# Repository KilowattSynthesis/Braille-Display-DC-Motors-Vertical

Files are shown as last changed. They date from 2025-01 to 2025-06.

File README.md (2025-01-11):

# Braille-Display-DC-Motors-Vertical

Braille display POC using 0408 DC motors, vertically inline under each dot, to spin a bolt for each dot. Includes CAD, PCB, and Firmware. 

**Type 5:** Vertical DC motors.

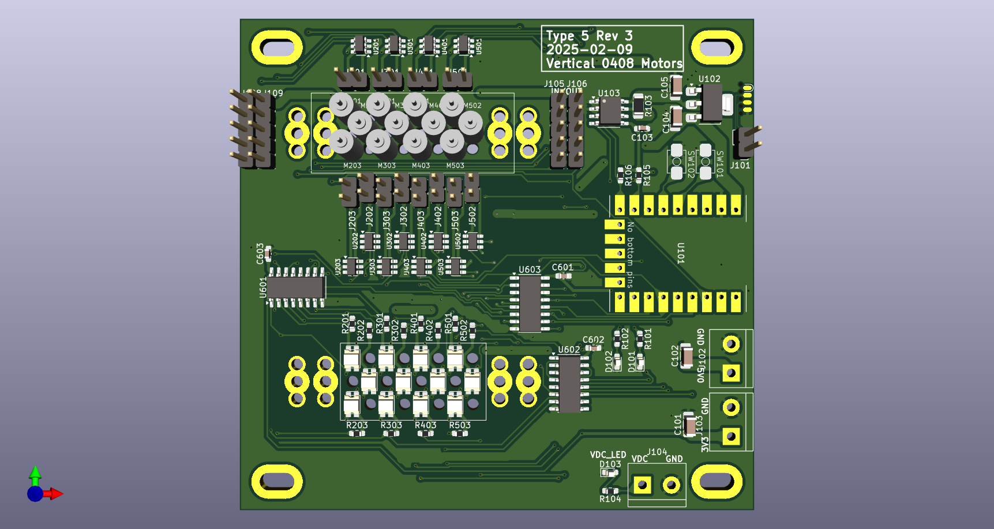
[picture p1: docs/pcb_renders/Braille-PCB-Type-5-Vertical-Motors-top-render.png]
Type 5 PCB Top Side Render


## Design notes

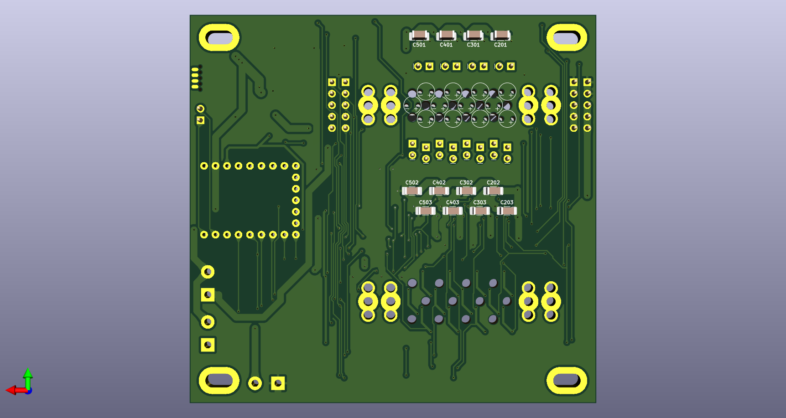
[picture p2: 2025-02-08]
docs/pcb_renders/Braille-PCB-Type-5-Vertical-Motors-bottom-render.png

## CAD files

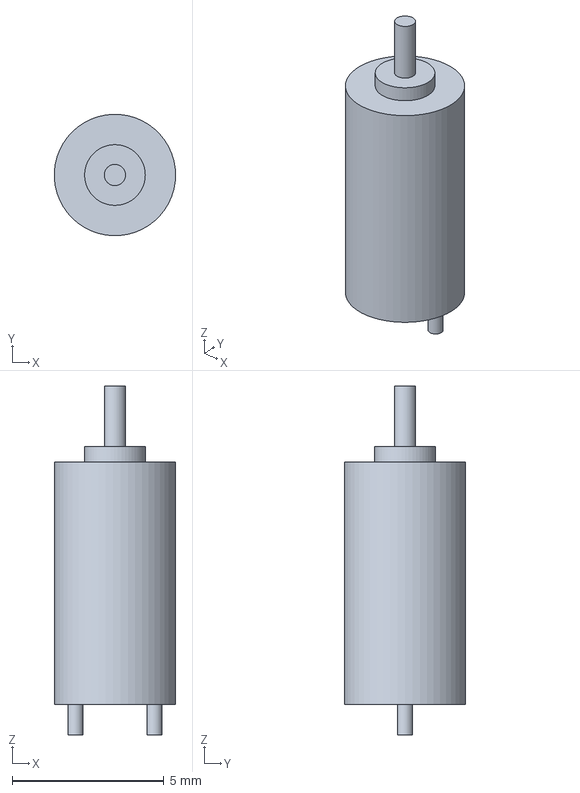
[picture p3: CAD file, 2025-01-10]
pcb/Braille-PCB-Type-5-Vertical-Motors/lib-cad/dc_motor_0408.step
4.00 x 4.00 x 11.5 mm

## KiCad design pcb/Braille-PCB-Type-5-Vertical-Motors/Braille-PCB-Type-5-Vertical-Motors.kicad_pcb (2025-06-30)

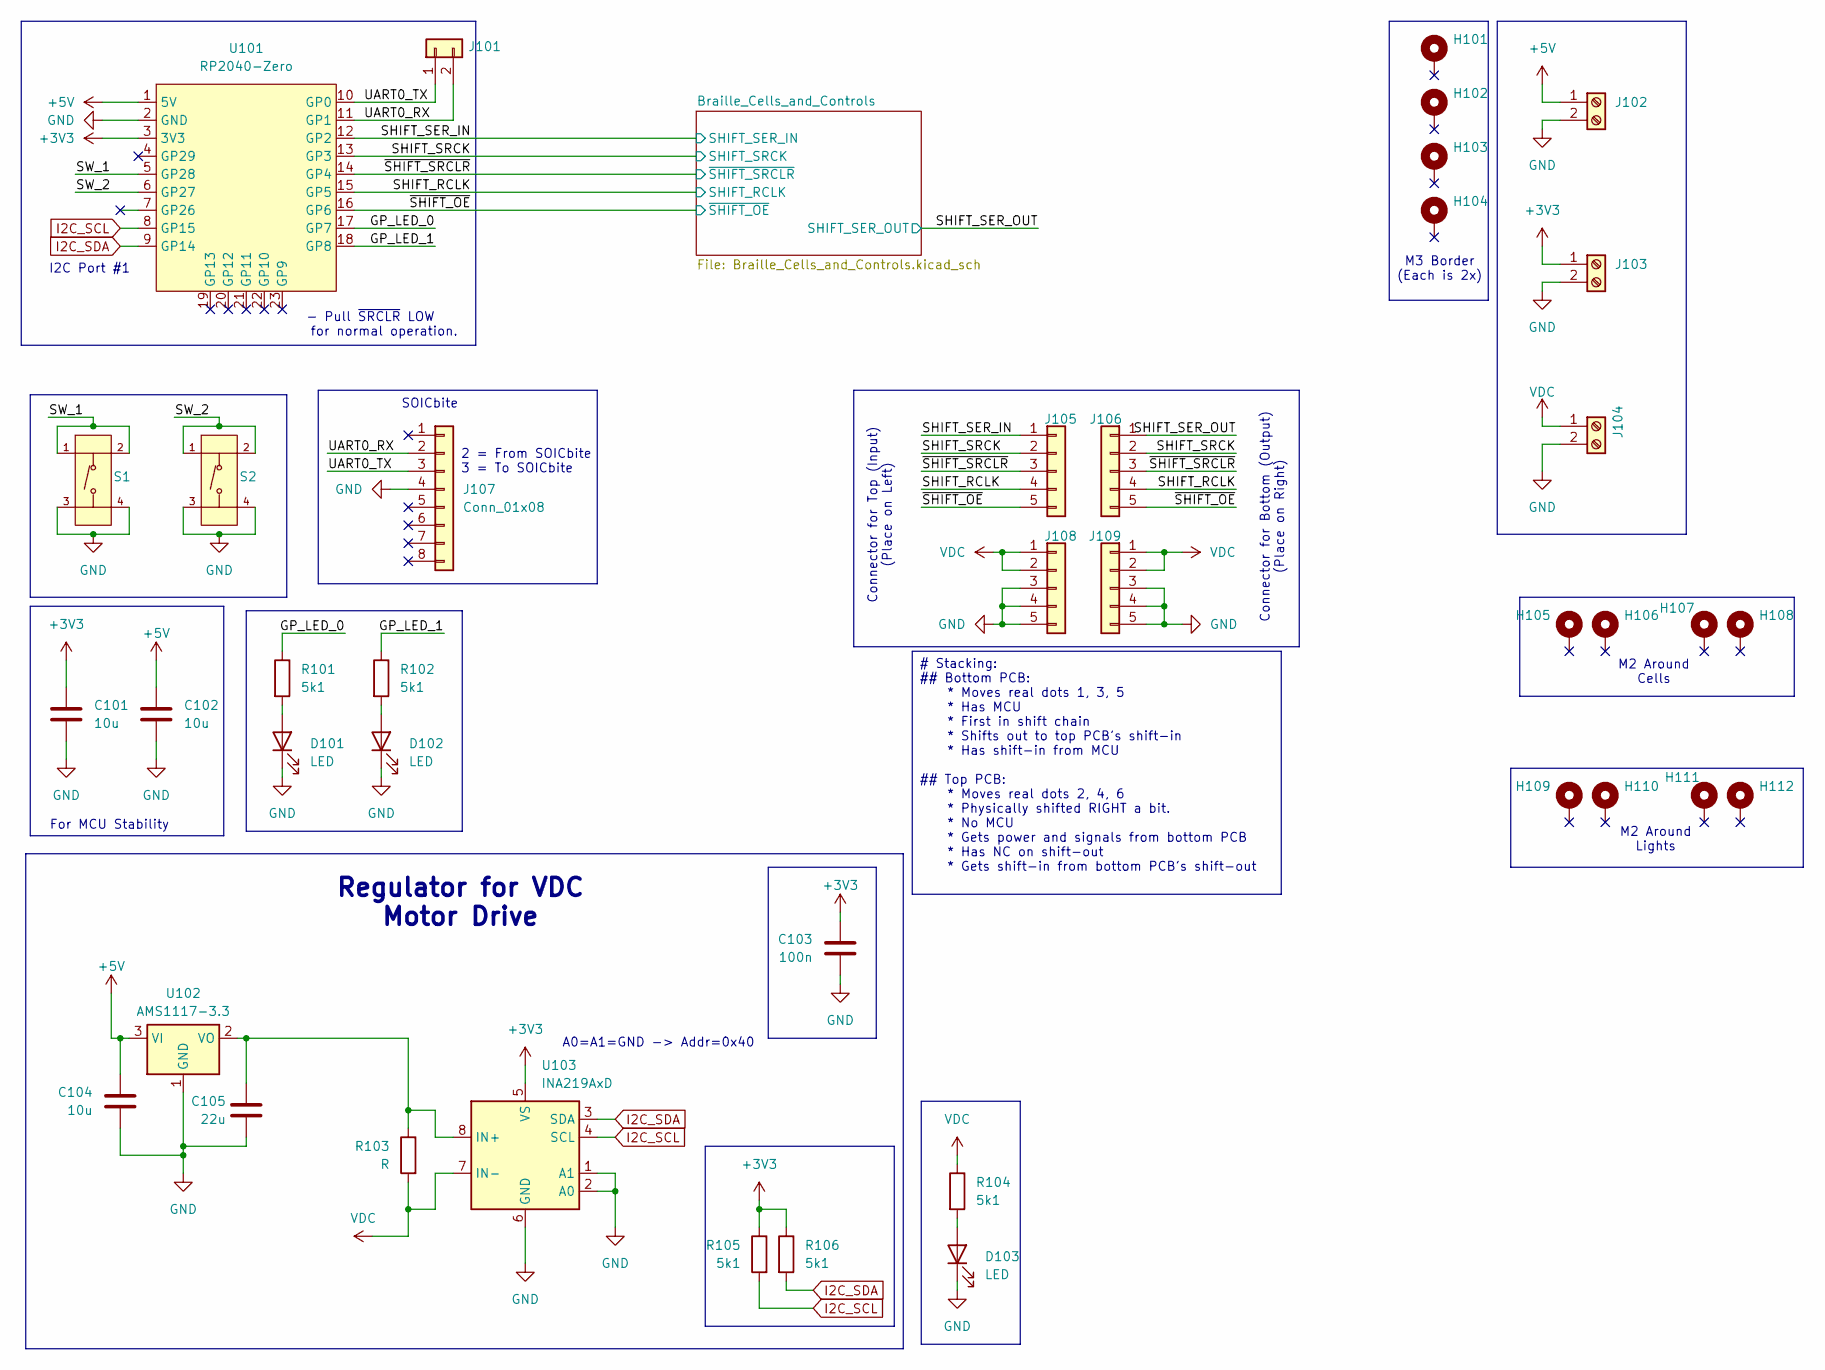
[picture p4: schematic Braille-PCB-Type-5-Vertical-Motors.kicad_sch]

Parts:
C101, C102, C104: 10u; C_1206_3216Metric_Pad1.33x1.80mm_HandSolder
C103: 100n; C_0603_1608Metric_Pad1.08x0.95mm_HandSolder
C105: 22u; C_1206_3216Metric_Pad1.33x1.80mm_HandSolder
D101, D102, D103: LED; LED_0603_1608Metric_Pad1.05x0.95mm_HandSolder
H101, H102, H103, H104: MountingHole_Pad; MountingHole_M3_2x_3mm_Pitch
H105, H106, H107, H108, H109, H110, H111, H112: MountingHole_Pad; Braille_Block_MountingHoles_M2_3x
J101: Conn_01x02; PinHeader_1x02_P2.54mm_Vertical
J102, J103, J104: Screw_Terminal_01x02; TerminalBlock_bornier-2_P5.08mm
J105, J106, J108, J109: Conn_01x05; PinHeader_1x05_P2.54mm_Vertical_Tight_Centered
J107: Conn_01x08; SOICbite_clipProgSmall
R101, R102, R104, R105, R106: 5k1; R_0603_1608Metric_Pad0.98x0.95mm_HandSolder
R103: R; R_1206_3216Metric_Pad1.30x1.75mm_HandSolder
S1, S2: Tactile Button, 160gf; SW-SMD_4P-L5.1-W5.1-P3.70-LS6.5-TL-2; Voltage Rating (Dc) 12V; Part TS-1187A-B-A-B; LCSC C318884
U101: RP2040-Zero; RP2040 Zero
U102: AMS1117-3.3; SOT-223-3_TabPin2
U103: INA219AxD; SOIC-8_3.9x4.9mm_P1.27mm

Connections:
+3V3: C101.1, C103.1, J103.1, R105.1, R106.1, U101.3 (3V3), U103.5 (VS); also elsewhere on the board
+5V: C102.1, C104.1, J102.1, U101.1 (5V), U102.3 (VI)
/GP_LED_0: R101.1, U101.17 (GP7)
/GP_LED_1: R102.1, U101.18 (GP8)
/SHIFT_RCLK: J105.4, J106.4, U101.15 (GP5); also elsewhere on the board
/SHIFT_SER_IN: J105.1, U101.12 (GP2); also elsewhere on the board
/SHIFT_SER_OUT: J106.1; also elsewhere on the board
/SHIFT_SRCK: J105.2, J106.2, U101.13 (GP3); also elsewhere on the board
/SW_1: S1.1 (A), S1.2 (B), U101.5 (GP28); also elsewhere on the board
/SW_2: S2.1 (A), S2.2 (B), U101.6 (GP27); also elsewhere on the board
/UART0_RX: J101.2, J107.2, U101.11 (GP1)
/UART0_TX: J101.1, J107.3, U101.10 (GP0)
/~SHIFT_OE: J105.5, J106.5, U101.16 (GP6); also elsewhere on the board
/~SHIFT_SRCLR: J105.3, J106.3, U101.14 (GP4); also elsewhere on the board
GND: C101.2, C102.2, C103.2, C104.2, C105.2, D101.1 (K), D102.1 (K), D103.1 (K), J102.2, J103.2, J104.2, J107.4, J108.3, J108.4, J108.5, J109.3, J109.4, J109.5, S1.3 (C), S1.4 (D), S2.3 (C), S2.4 (D), U101.2 (GND), U102.1 (GND), U103.1 (A1), U103.2 (A0), U103.6 (GND); also elsewhere on the board
I2C_SCL: R105.2, U101.8 (GP15), U103.4 (SCL)
I2C_SDA: R106.2, U101.9 (GP14), U103.3 (SDA)
unnamed: D101.2 (A), R101.2
unnamed: D102.2 (A), R102.2
unnamed: D103.2 (A), R104.2
unnamed: C105.1, R103.1, U102.2 (VO), U103.8 (IN+)
VDC: J104.1, J108.1, J108.2, J109.1, J109.2, R103.2, R104.1, U103.7 (IN-); also elsewhere on the board

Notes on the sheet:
SOICbite
2 = From SOICbite 3 = To SOICbite
M2 Around Cells
For MCU Stability
A0=A1=GND -> Addr=0x40
I2C Port #1
- Pull ~{SRCLR} LOW for normal operation.
M3 Border (Each is 2x)
M2 Around Lights
Connector for Top (Input) (Place on Left)
Connector for Bottom (Output) (Place on Right)
Regulator for VDC Motor Drive
# Stacking: ## Bottom PCB: * Moves real dots 1, 3, 5 * Has MCU * First in shift chain * Shifts out to top PCB's shift-in * Has shift-in from MCU ## Top PCB: * Moves real dots 2, 4, 6 * Physically shifted RIGHT a bit. * No MCU * Gets power and signals from bottom PCB * Has NC on shift-out * Gets shi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

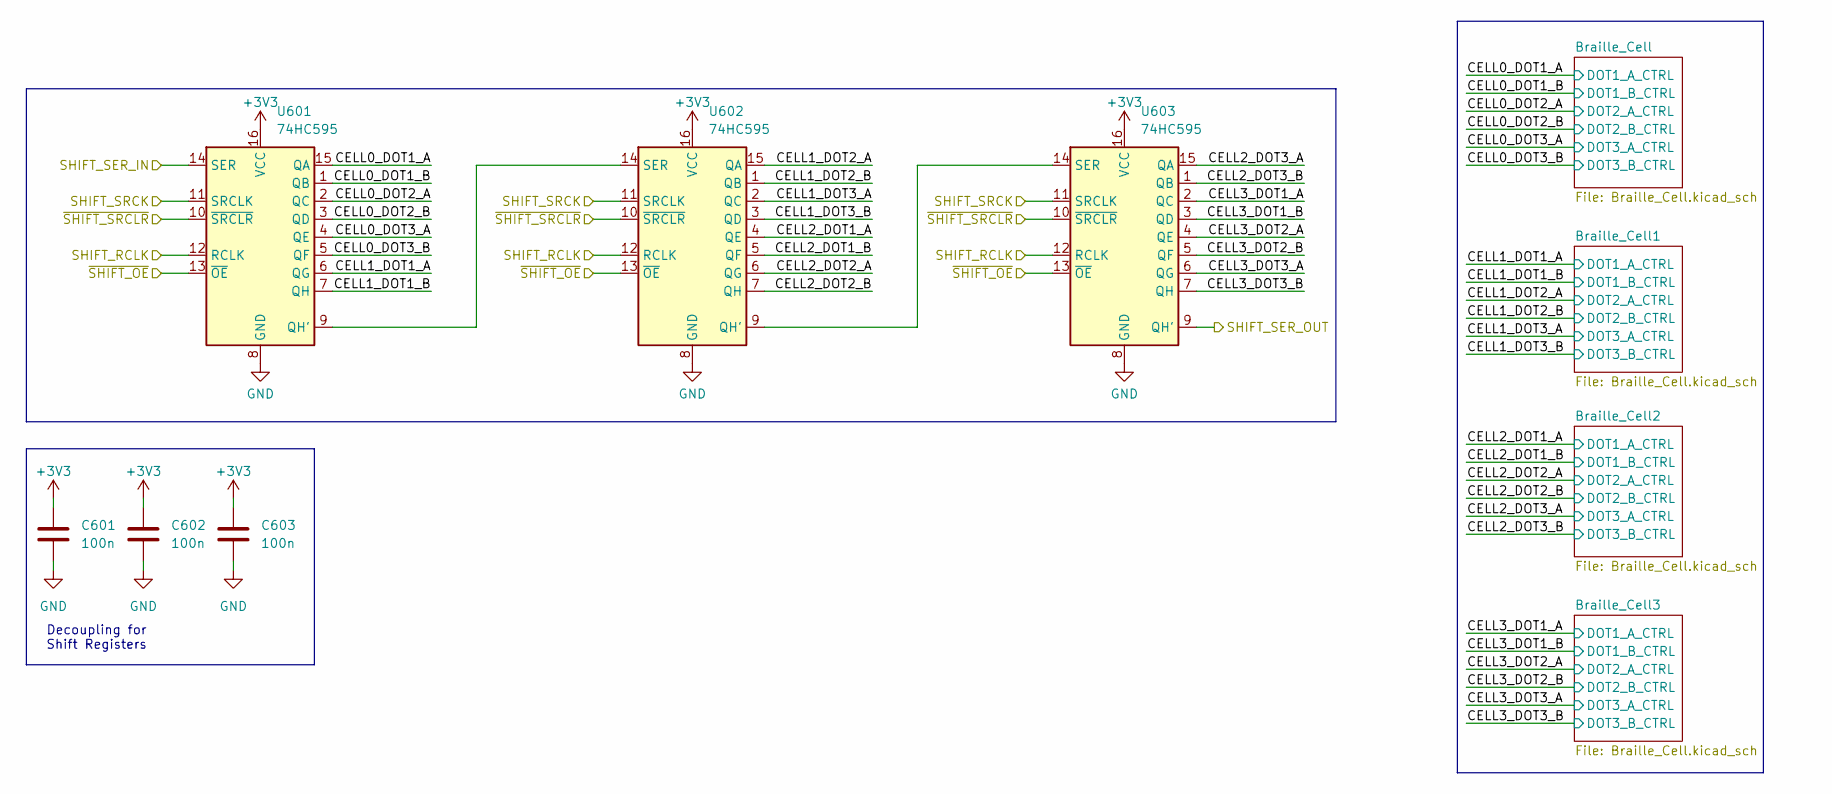
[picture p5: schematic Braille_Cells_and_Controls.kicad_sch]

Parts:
C601, C602, C603: 100n; C_0603_1608Metric_Pad1.08x0.95mm_HandSolder
U601, U602, U603: 74HC595; SOP-16_3.9x9.9mm_P1.27mm

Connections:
+3V3: C601.1, C602.1, C603.1, U601.16 (VCC), U602.16 (VCC), U603.16 (VCC); also elsewhere on the board
/Braille_Cells_and_Controls/CELL0_DOT1_A: U601.15 (QA); also elsewhere on the board
/Braille_Cells_and_Controls/CELL0_DOT1_B: U601.1 (QB); also elsewhere on the board
/Braille_Cells_and_Controls/CELL0_DOT2_A: U601.2 (QC); also elsewhere on the board
/Braille_Cells_and_Controls/CELL0_DOT2_B: U601.3 (QD); also elsewhere on the board
/Braille_Cells_and_Controls/CELL0_DOT3_A: U601.4 (QE); also elsewhere on the board
/Braille_Cells_and_Controls/CELL0_DOT3_B: U601.5 (QF); also elsewhere on the board
/Braille_Cells_and_Controls/CELL1_DOT1_A: U601.6 (QG); also elsewhere on the board
/Braille_Cells_and_Controls/CELL1_DOT1_B: U601.7 (QH); also elsewhere on the board
/Braille_Cells_and_Controls/CELL1_DOT2_A: U602.15 (QA); also elsewhere on the board
/Braille_Cells_and_Controls/CELL1_DOT2_B: U602.1 (QB); also elsewhere on the board
/Braille_Cells_and_Controls/CELL1_DOT3_A: U602.2 (QC); also elsewhere on the board
/Braille_Cells_and_Controls/CELL1_DOT3_B: U602.3 (QD); also elsewhere on the board
/Braille_Cells_and_Controls/CELL2_DOT1_A: U602.4 (QE); also elsewhere on the board
/Braille_Cells_and_Controls/CELL2_DOT1_B: U602.5 (QF); also elsewhere on the board
/Braille_Cells_and_Controls/CELL2_DOT2_A: U602.6 (QG); also elsewhere on the board
/Braille_Cells_and_Controls/CELL2_DOT2_B: U602.7 (QH); also elsewhere on the board
/Braille_Cells_and_Controls/CELL2_DOT3_A: U603.15 (QA); also elsewhere on the board
/Braille_Cells_and_Controls/CELL2_DOT3_B: U603.1 (QB); also elsewhere on the board
/Braille_Cells_and_Controls/CELL3_DOT1_A: U603.2 (QC); also elsewhere on the board
/Braille_Cells_and_Controls/CELL3_DOT1_B: U603.3 (QD); also elsewhere on the board
/Braille_Cells_and_Controls/CELL3_DOT2_A: U603.4 (QE); also elsewhere on the board
/Braille_Cells_and_Controls/CELL3_DOT2_B: U603.5 (QF); also elsewhere on the board
/Braille_Cells_and_Controls/CELL3_DOT3_A: U603.6 (QG); also elsewhere on the board
/Braille_Cells_and_Controls/CELL3_DOT3_B: U603.7 (QH); also elsewhere on the board
/SHIFT_RCLK: U601.12 (RCLK), U602.12 (RCLK), U603.12 (RCLK); also elsewhere on the board
/SHIFT_SER_IN: U601.14 (SER); also elsewhere on the board
/SHIFT_SER_OUT: U603.9 (QH'); also elsewhere on the board
/SHIFT_SRCK: U601.11 (SRCLK), U602.11 (SRCLK), U603.11 (SRCLK); also elsewhere on the board
/~SHIFT_OE: U601.13 (~OE), U602.13 (~OE), U603.13 (~OE); also elsewhere on the board
/~SHIFT_SRCLR: U601.10 (~SRCLR), U602.10 (~SRCLR), U603.10 (~SRCLR); also elsewhere on the board
GND: C601.2, C602.2, C603.2, U601.8 (GND), U602.8 (GND), U603.8 (GND); also elsewhere on the board
unnamed: U601.9 (QH'), U602.14 (SER)
unnamed: U602.9 (QH'), U603.14 (SER)

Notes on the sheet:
Decoupling for Shift Registers

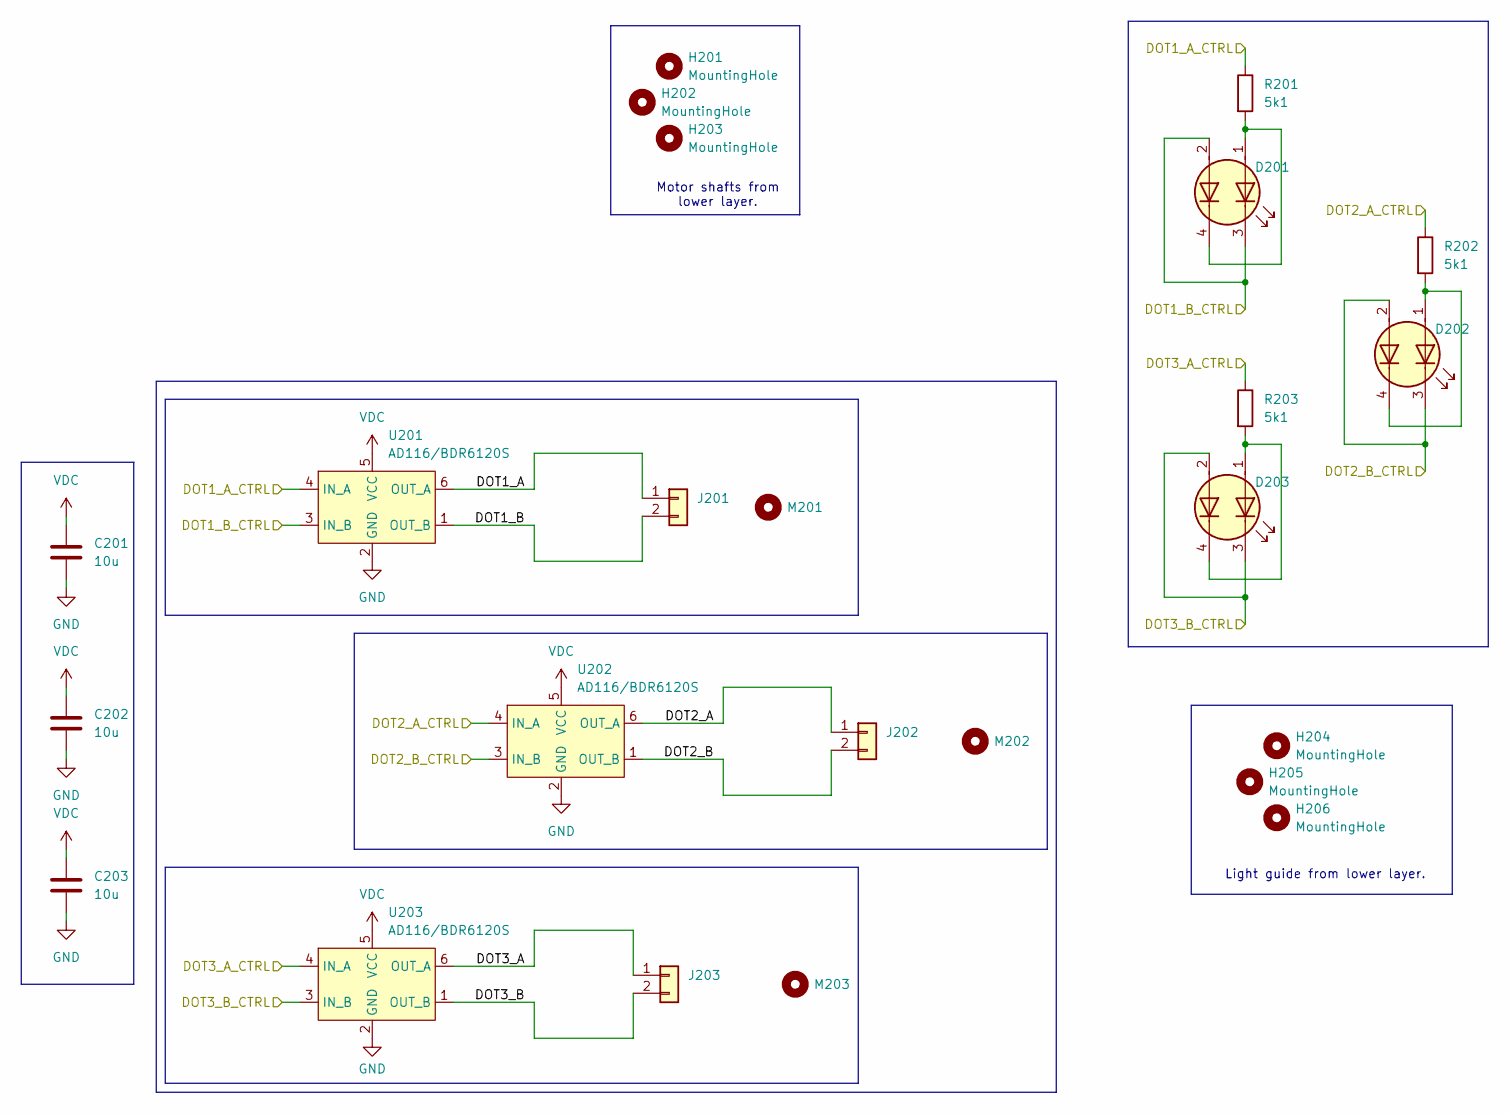
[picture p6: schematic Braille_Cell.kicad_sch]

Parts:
C201, C202, C203: 10u; C_1206_3216Metric_Pad1.33x1.80mm_HandSolder
D201, D202, D203: LED_Dual_AAKK; LED_1206_Bicolor_AAKK
H201, H202, H203, H204, H205, H206: MountingHole; Hole_for_Motor_Shaft
J201, J202, J203: Conn_01x02; PinHeader_1x02_P2.54mm_Vertical_Tight_Centered
M201, M202, M203: MountingHole; Motor_Tiny_0408_Vertical
R201, R202, R203: 5k1; R_0603_1608Metric_Pad0.98x0.95mm_HandSolder
U201, U202, U203: AD116/BDR6120S; SOT-23-6

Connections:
/Braille_Cells_and_Controls/Braille_Cell/DOT1_A: J201.1, U201.6 (OUT_A)
/Braille_Cells_and_Controls/Braille_Cell/DOT1_B: J201.2, U201.1 (OUT_B)
/Braille_Cells_and_Controls/Braille_Cell/DOT2_A: J202.1, U202.6 (OUT_A)
/Braille_Cells_and_Controls/Braille_Cell/DOT2_B: J202.2, U202.1 (OUT_B)
/Braille_Cells_and_Controls/Braille_Cell/DOT3_A: J203.1, U203.6 (OUT_A)
/Braille_Cells_and_Controls/Braille_Cell/DOT3_B: J203.2, U203.1 (OUT_B)
/Braille_Cells_and_Controls/CELL0_DOT1_A: R201.1, U201.4 (IN_A); also elsewhere on the board
/Braille_Cells_and_Controls/CELL0_DOT1_B: D201.2 (A2), D201.3 (K1), U201.3 (IN_B); also elsewhere on the board
/Braille_Cells_and_Controls/CELL0_DOT2_A: R202.1, U202.4 (IN_A); also elsewhere on the board
/Braille_Cells_and_Controls/CELL0_DOT2_B: D202.2 (A2), D202.3 (K1), U202.3 (IN_B); also elsewhere on the board
/Braille_Cells_and_Controls/CELL0_DOT3_A: R203.1, U203.4 (IN_A); also elsewhere on the board
/Braille_Cells_and_Controls/CELL0_DOT3_B: D203.2 (A2), D203.3 (K1), U203.3 (IN_B); also elsewhere on the board
GND: C201.2, C202.2, C203.2, U201.2 (GND), U202.2 (GND), U203.2 (GND); also elsewhere on the board
unnamed: D201.1 (A1), D201.4 (K2), R201.2
unnamed: D202.1 (A1), D202.4 (K2), R202.2
unnamed: D203.1 (A1), D203.4 (K2), R203.2
VDC: C201.1, C202.1, C203.1, U201.5 (VCC), U202.5 (VCC), U203.5 (VCC); also elsewhere on the board

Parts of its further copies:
C301, C302, C303, C401, C402, C403, C501, C502, C503: 10u; C_1206_3216Metric_Pad1.33x1.80mm_HandSolder
D301, D302, D303, D401, D402, D403, D501, D502, D503: LED_Dual_AAKK; LED_1206_Bicolor_AAKK
H301, H302, H303, H304, H305, H306, H401, H402, H403, H404, H405, H406, H501, H502, H503, H504, H505, H506: MountingHole; Hole_for_Motor_Shaft
J301, J302, J303, J401, J402, J403, J501, J502, J503: Conn_01x02; PinHeader_1x02_P2.54mm_Vertical_Tight_Centered
M301, M302, M303, M401, M402, M403, M501, M502, M503: MountingHole; Motor_Tiny_0408_Vertical
R301, R302, R303, R401, R402, R403, R501, R502, R503: 5k1; R_0603_1608Metric_Pad0.98x0.95mm_HandSolder

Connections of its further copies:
/Braille_Cells_and_Controls/Braille_Cell1/DOT1_A: J301.1; also elsewhere on the board
/Braille_Cells_and_Controls/Braille_Cell1/DOT1_B: J301.2; also elsewhere on the board
/Braille_Cells_and_Controls/Braille_Cell1/DOT2_A: J302.1; also elsewhere on the board
/Braille_Cells_and_Controls/Braille_Cell1/DOT2_B: J302.2; also elsewhere on the board
/Braille_Cells_and_Controls/Braille_Cell1/DOT3_A: J303.1; also elsewhere on the board
/Braille_Cells_and_Controls/Braille_Cell1/DOT3_B: J303.2; also elsewhere on the board
/Braille_Cells_and_Controls/Braille_Cell2/DOT1_A: J401.1; also elsewhere on the board
/Braille_Cells_and_Controls/Braille_Cell2/DOT1_B: J401.2; also elsewhere on the board
/Braille_Cells_and_Controls/Braille_Cell2/DOT2_A: J402.1; also elsewhere on the board
/Braille_Cells_and_Controls/Braille_Cell2/DOT2_B: J402.2; also elsewhere on the board
/Braille_Cells_and_Controls/Braille_Cell2/DOT3_A: J403.1; also elsewhere on the board
/Braille_Cells_and_Controls/Braille_Cell2/DOT3_B: J403.2; also elsewhere on the board
/Braille_Cells_and_Controls/Braille_Cell3/DOT1_A: J501.1; also elsewhere on the board
/Braille_Cells_and_Controls/Braille_Cell3/DOT1_B: J501.2; also elsewhere on the board
/Braille_Cells_and_Controls/Braille_Cell3/DOT2_A: J502.1; also elsewhere on the board
/Braille_Cells_and_Controls/Braille_Cell3/DOT2_B: J502.2; also elsewhere on the board
/Braille_Cells_and_Controls/Braille_Cell3/DOT3_A: J503.1; also elsewhere on the board
/Braille_Cells_and_Controls/Braille_Cell3/DOT3_B: J503.2; also elsewhere on the board
/Braille_Cells_and_Controls/CELL1_DOT1_A: R301.1; also elsewhere on the board
/Braille_Cells_and_Controls/CELL1_DOT1_B: D301.2 (A2), D301.3 (K1); also elsewhere on the board
/Braille_Cells_and_Controls/CELL1_DOT2_A: R302.1; also elsewhere on the board
/Braille_Cells_and_Controls/CELL1_DOT2_B: D302.2 (A2), D302.3 (K1); also elsewhere on the board
/Braille_Cells_and_Controls/CELL1_DOT3_A: R303.1; also elsewhere on the board
/Braille_Cells_and_Controls/CELL1_DOT3_B: D303.2 (A2), D303.3 (K1); also elsewhere on the board
/Braille_Cells_and_Controls/CELL2_DOT1_A: R401.1; also elsewhere on the board
/Braille_Cells_and_Controls/CELL2_DOT1_B: D401.2 (A2), D401.3 (K1); also elsewhere on the board
/Braille_Cells_and_Controls/CELL2_DOT2_A: R402.1; also elsewhere on the board
/Braille_Cells_and_Controls/CELL2_DOT2_B: D402.2 (A2), D402.3 (K1); also elsewhere on the board
/Braille_Cells_and_Controls/CELL2_DOT3_A: R403.1; also elsewhere on the board
/Braille_Cells_and_Controls/CELL2_DOT3_B: D403.2 (A2), D403.3 (K1); also elsewhere on the board
/Braille_Cells_and_Controls/CELL3_DOT1_A: R501.1; also elsewhere on the board
/Braille_Cells_and_Controls/CELL3_DOT1_B: D501.2 (A2), D501.3 (K1); also elsewhere on the board
/Braille_Cells_and_Controls/CELL3_DOT2_A: R502.1; also elsewhere on the board
/Braille_Cells_and_Controls/CELL3_DOT2_B: D502.2 (A2), D502.3 (K1); also elsewhere on the board
/Braille_Cells_and_Controls/CELL3_DOT3_A: R503.1; also elsewhere on the board
/Braille_Cells_and_Controls/CELL3_DOT3_B: D503.2 (A2), D503.3 (K1); also elsewhere on the board
GND: C301.2, C302.2, C303.2, C401.2, C402.2, C403.2, C501.2, C502.2, C503.2; also elsewhere on the board
unnamed: D301.1 (A1), D301.4 (K2), R301.2
unnamed: D302.1 (A1), D302.4 (K2), R302.2
unnamed: D303.1 (A1), D303.4 (K2), R303.2
unnamed: D401.1 (A1), D401.4 (K2), R401.2
unnamed: D402.1 (A1), D402.4 (K2), R402.2
unnamed: D403.1 (A1), D403.4 (K2), R403.2
unnamed: D501.1 (A1), D501.4 (K2), R501.2
unnamed: D502.1 (A1), D502.4 (K2), R502.2
unnamed: D503.1 (A1), D503.4 (K2), R503.2
VDC: C301.1, C302.1, C303.1, C401.1, C402.1, C403.1, C501.1, C502.1, C503.1; also elsewhere on the board

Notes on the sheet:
Light guide from lower layer.
Motor shafts from lower layer.

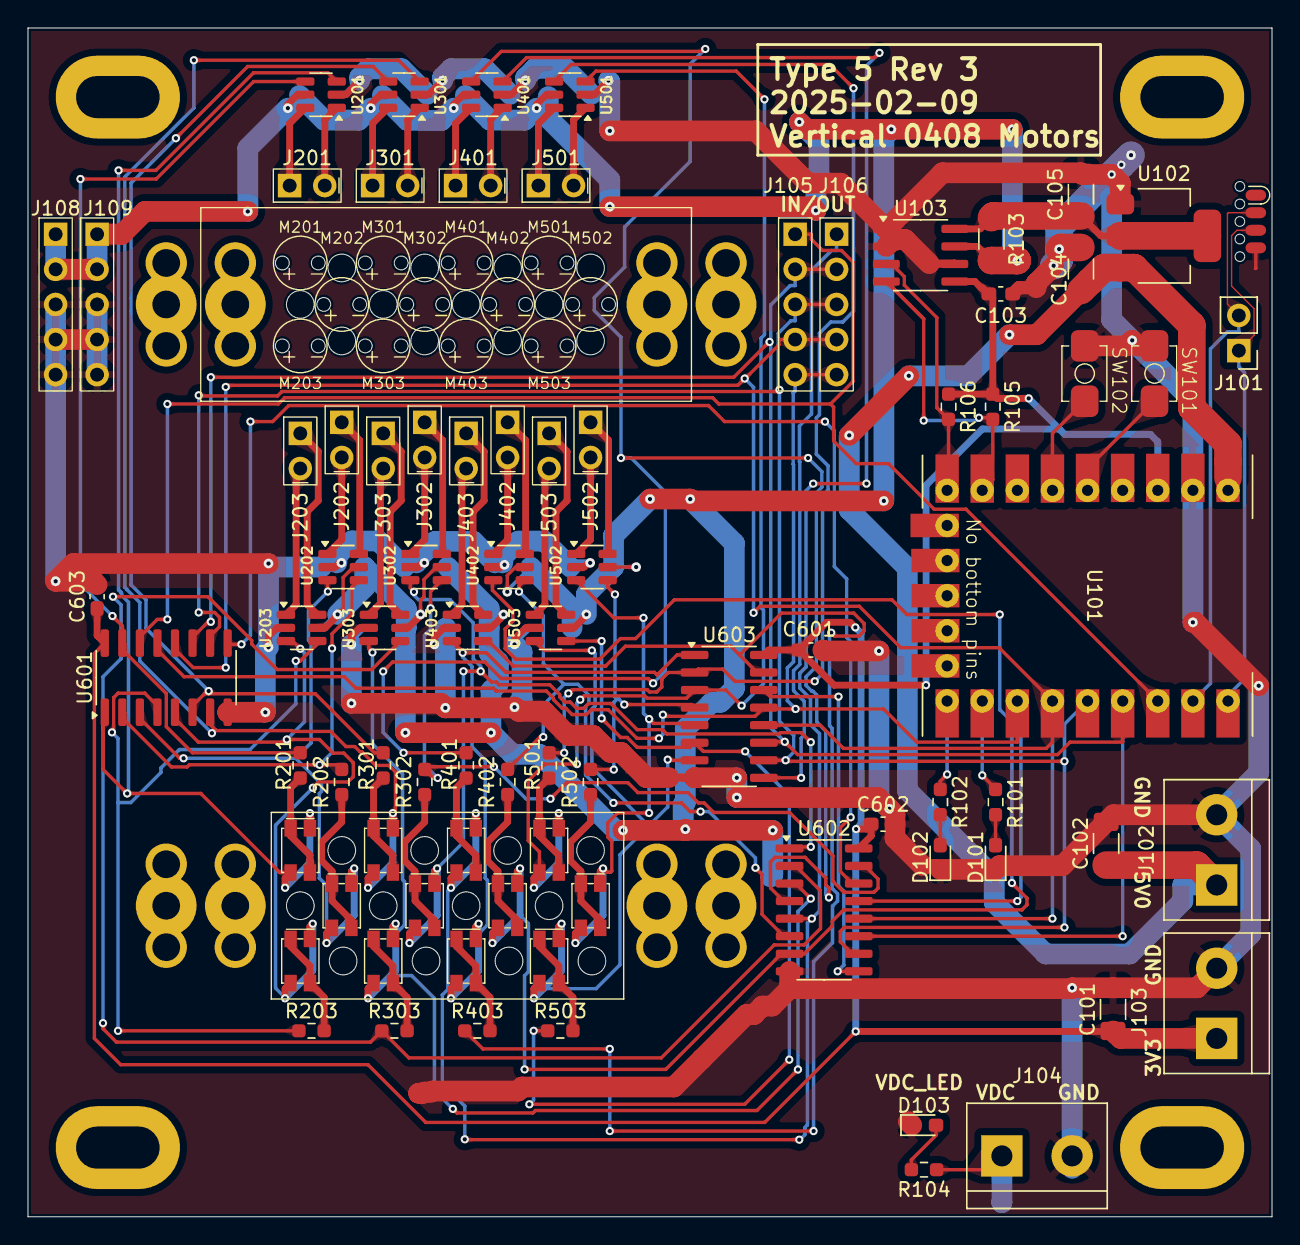
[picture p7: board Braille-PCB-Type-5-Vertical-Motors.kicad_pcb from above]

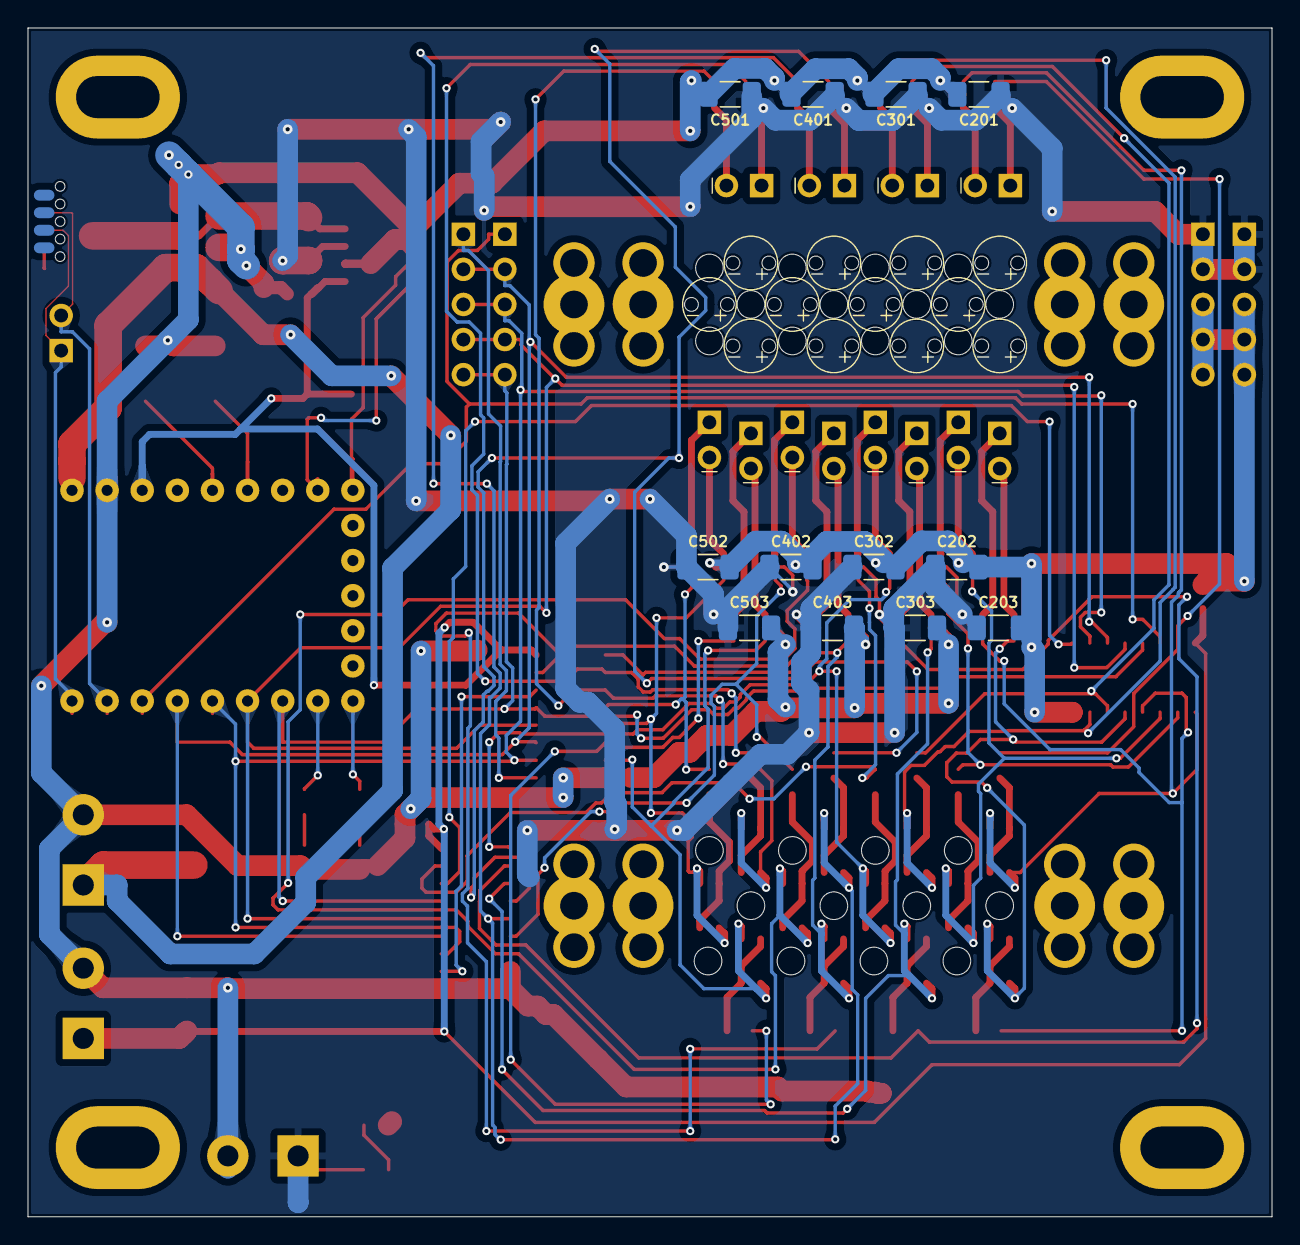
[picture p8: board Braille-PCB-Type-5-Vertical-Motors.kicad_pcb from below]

Board: 2 copper layers, 90.0 x 86.0 mm, 142 parts (12 on the bottom side), 84 nets.

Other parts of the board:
SW101, SW102: SW_Push; PushButtonSMD_2.93x3.9
U301, U302, U303, U401, U402, U403, U501, U502, U503: AD116; SOT-23-6

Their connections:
/Braille_Cells_and_Controls/Braille_Cell1/DOT1_A: U301.6 (OUT_A); also elsewhere on the board
/Braille_Cells_and_Controls/Braille_Cell1/DOT1_B: U301.1 (OUT_B); also elsewhere on the board
/Braille_Cells_and_Controls/Braille_Cell1/DOT2_A: U302.6 (OUT_A); also elsewhere on the board
/Braille_Cells_and_Controls/Braille_Cell1/DOT2_B: U302.1 (OUT_B); also elsewhere on the board
/Braille_Cells_and_Controls/Braille_Cell1/DOT3_A: U303.6 (OUT_A); also elsewhere on the board
/Braille_Cells_and_Controls/Braille_Cell1/DOT3_B: U303.1 (OUT_B); also elsewhere on the board
/Braille_Cells_and_Controls/Braille_Cell2/DOT1_A: U401.6 (OUT_A); also elsewhere on the board
/Braille_Cells_and_Controls/Braille_Cell2/DOT1_B: U401.1 (OUT_B); also elsewhere on the board
/Braille_Cells_and_Controls/Braille_Cell2/DOT2_A: U402.6 (OUT_A); also elsewhere on the board
/Braille_Cells_and_Controls/Braille_Cell2/DOT2_B: U402.1 (OUT_B); also elsewhere on the board
/Braille_Cells_and_Controls/Braille_Cell2/DOT3_A: U403.6 (OUT_A); also elsewhere on the board
/Braille_Cells_and_Controls/Braille_Cell2/DOT3_B: U403.1 (OUT_B); also elsewhere on the board
/Braille_Cells_and_Controls/Braille_Cell3/DOT1_A: U501.6 (OUT_A); also elsewhere on the board
/Braille_Cells_and_Controls/Braille_Cell3/DOT1_B: U501.1 (OUT_B); also elsewhere on the board
/Braille_Cells_and_Controls/Braille_Cell3/DOT2_A: U502.6 (OUT_A); also elsewhere on the board
/Braille_Cells_and_Controls/Braille_Cell3/DOT2_B: U502.1 (OUT_B); also elsewhere on the board
/Braille_Cells_and_Controls/Braille_Cell3/DOT3_A: U503.6 (OUT_A); also elsewhere on the board
/Braille_Cells_and_Controls/Braille_Cell3/DOT3_B: U503.1 (OUT_B); also elsewhere on the board
/Braille_Cells_and_Controls/CELL1_DOT1_A: U301.4 (IN_A); also elsewhere on the board
/Braille_Cells_and_Controls/CELL1_DOT1_B: U301.3 (IN_B); also elsewhere on the board
/Braille_Cells_and_Controls/CELL1_DOT2_A: U302.4 (IN_A); also elsewhere on the board
/Braille_Cells_and_Controls/CELL1_DOT2_B: U302.3 (IN_B); also elsewhere on the board
/Braille_Cells_and_Controls/CELL1_DOT3_A: U303.4 (IN_A); also elsewhere on the board
/Braille_Cells_and_Controls/CELL1_DOT3_B: U303.3 (IN_B); also elsewhere on the board
/Braille_Cells_and_Controls/CELL2_DOT1_A: U401.4 (IN_A); also elsewhere on the board
/Braille_Cells_and_Controls/CELL2_DOT1_B: U401.3 (IN_B); also elsewhere on the board
/Braille_Cells_and_Controls/CELL2_DOT2_A: U402.4 (IN_A); also elsewhere on the board
/Braille_Cells_and_Controls/CELL2_DOT2_B: U402.3 (IN_B); also elsewhere on the board
/Braille_Cells_and_Controls/CELL2_DOT3_A: U403.4 (IN_A); also elsewhere on the board
/Braille_Cells_and_Controls/CELL2_DOT3_B: U403.3 (IN_B); also elsewhere on the board
/Braille_Cells_and_Controls/CELL3_DOT1_A: U501.4 (IN_A); also elsewhere on the board
/Braille_Cells_and_Controls/CELL3_DOT1_B: U501.3 (IN_B); also elsewhere on the board
/Braille_Cells_and_Controls/CELL3_DOT2_A: U502.4 (IN_A); also elsewhere on the board
/Braille_Cells_and_Controls/CELL3_DOT2_B: U502.3 (IN_B); also elsewhere on the board
/Braille_Cells_and_Controls/CELL3_DOT3_A: U503.4 (IN_A); also elsewhere on the board
/Braille_Cells_and_Controls/CELL3_DOT3_B: U503.3 (IN_B); also elsewhere on the board
/SW_1: SW101.2; also elsewhere on the board
/SW_2: SW102.2; also elsewhere on the board
GND: SW101.1, SW102.1, U301.2 (GND), U302.2 (GND), U303.2 (GND), U401.2 (GND), U402.2 (GND), U403.2 (GND), U501.2 (GND), U502.2 (GND), U503.2 (GND); also elsewhere on the board
VDC: U301.5 (VCC), U302.5 (VCC), U303.5 (VCC), U401.5 (VCC), U402.5 (VCC), U403.5 (VCC), U501.5 (VCC), U502.5 (VCC), U503.5 (VCC); also elsewhere on the board

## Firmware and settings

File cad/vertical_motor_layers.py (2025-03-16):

"""Using a layer of screws (like the `cnc_plotter` branch), make motor holder.

Intended as a proof of concept to see how the motors can fit.

Conclusion: At 2.5mm pitch, Motor OD=4mm, H=8mm motors can't really fit.

Conclusion: At 3mm pitch though, Motor OD=4mm, H=8mm motors can totally fit! Just need
to bend their shafts a bit to make them mate with the screws!
"""

import copy
import json
from dataclasses import dataclass
from datetime import UTC, datetime
from functools import reduce
from itertools import product
from math import atan2, degrees, sqrt
from pathlib import Path

import bd_warehouse.thread
import build123d as bd
import build123d_ease as bde
from build123d_ease import show
from loguru import logger


@dataclass(kw_only=True)
class HousingSpec:
    """Specification for braille cell in general."""

    motor_pitch_x: float = 3
    motor_pitch_y: float = 2.64  # Solved below to hold motor tightly.
    dot_pitch_x: float = 2.5
    dot_pitch_y: float = 2.5
    cell_pitch_x: float = 6
    cell_pitch_y: float = 10

    dot_count_x: int = 2
    dot_count_y: int = 3

    motor_body_od: float = 4.5
    motor_body_length: float = 8.0 + 1.0  # Extra 1mm for fit (esp for bottom).

    # Main gap for top motor. 8mm seems workable (with 6mm bolts).
    # 10mm good for paper/wires as couplers.
    # 7mm probably good for 5mm springs with 6mm bolts.
    gap_above_top_motor: float = 7.0

    cell_count_x: int = 4
    cell_count_y: int = 1

    total_y: float = 15

    # Distance from outer dots to mounting holes. PCB property.
    x_dist_dots_to_mounting_holes: float = 5.0

    mounting_hole_spacing_y: float = 3
    mounting_hole_id: float = 1.8  # Thread-forming screws from bottom.
    mounting_hole_peg_od: float = 2
    mounting_hole_peg_length: float = 1.5
    meat_above_peg: float = 3

    border_x: float = 5

    top_plate_thickness: float = 2
    top_plate_tap_hole_diameter: float = 1.25  # For M1.6, drill 1.25mm hole.

    top_plate_dot_hole_thread_diameter: float = 1.6
    top_plate_dot_hole_thread_pitch: float = 0.35

    remove_thin_walls: bool = True

    slice_thickness: float = 7  # Just under the motor_length.

    @property
    def dist_between_motor_walls(self) -> float:
        """Distance between motor walls in a layer."""
        return self.motor_pitch_x * 2 - self.motor_body_od

    @property
    def mounting_hole_spacing_x(self) -> float:
        """Spacing between the mounting holes, in X axis."""
        return (
            self.x_dist_dots_to_mounting_holes * 2
            + self.cell_pitch_x * (self.cell_count_x - 1)
            + self.dot_pitch_x
        )

    @property
    def total_x(self) -> float:
        """Total width of the braille housing."""
        return self.mounting_hole_spacing_x + self.mounting_hole_id + self.border_x * 2

    @property
    def total_z(self) -> float:
        """Total thickness of the housing."""
        return self.motor_body_length + self.gap_above_top_motor

    def __post_init__(self) -> None:
        """Post initialization checks."""
        hypot_len = (self.motor_pitch_x**2 + self.motor_pitch_y**2) ** 0.5

        data = {
            "hypot_len": round(hypot_len, 2),  # Forced to match `motor_od`.
            "total_x": self.total_x,
            "total_y": self.total_y,
            "total_z": self.total_z,
            "dist_between_motor_walls": self.dist_between_motor_walls,
            "threads_in_top_plate": round(
                self.top_plate_thickness / self.top_plate_dot_hole_thread_pitch, 1
            ),
        }

        logger.info(json.dumps(data, indent=2))

    def deep_copy(self) -> "HousingSpec":
        """Copy the current spec."""
        return copy.deepcopy(self)


def motor_housing(spec: HousingSpec) -> bd.Part | bd.Compound:
    """Make housing with the placement from the demo.

    Args:
        spec: The specification for the housing.

    """
    p = bd.Part(None)

    p += bd.Box(
        spec.total_x,
        spec.total_y,
        spec.total_z,
        align=bde.align.ANCHOR_BOTTOM,
    )

    # Create the motor holes.
    motor_coords: list[tuple[float, float]] = []
    for dot_num, (cell_x, cell_y, offset_x, offset_y) in enumerate(
        product(
            bde.evenly_space_with_center(
                count=spec.cell_count_x,
                spacing=spec.cell_pitch_x,
            ),
            bde.evenly_space_with_center(
                count=spec.cell_count_y,
                spacing=spec.cell_pitch_y,
            ),
            bde.evenly_space_with_center(count=2, spacing=1),
            bde.evenly_space_with_center(count=3, spacing=1),
        ),
    ):
        motor_x = cell_x + offset_x * spec.motor_pitch_x
        motor_y = cell_y + offset_y * spec.motor_pitch_y

        is_motor_spot: bool = (dot_num % 2) == 0

        # Skip places where there's not a motor (checkerboard).
        if not is_motor_spot:
            continue

        # Store the motor coordinates for later.
        motor_coords.append((motor_x, motor_y))

        # Create the motor hole.
        p -= bd.Cylinder(
            spec.motor_body_od / 2,
            spec.motor_body_length,
            align=bde.align.ANCHOR_BOTTOM,
        ).translate((motor_x, motor_y, 0))

    if spec.remove_thin_walls:
        # Subtract a hull of the centers of the motor holes.
        p -= bd.extrude(
            bd.make_hull(
                reduce(
                    lambda a, b: a + b,
                    [
                        bd.Circle(radius=0.2).translate((motor_x, motor_y)).edges()
                        for motor_x, motor_y in motor_coords
                    ],
                )
            ),
            amount=spec.motor_body_length,
        )

    # Remove the mounting holes.
    for x_val, y_val in product(
        bde.evenly_space_with_center(
            count=2,
            spacing=spec.mounting_hole_spacing_x,
        ),
        bde.evenly_space_with_center(
            count=3,
            spacing=spec.mounting_hole_spacing_y,
        ),
    ):
        p -= bd.Pos(
            X=x_val,
            Y=y_val,
            Z=(0 if y_val == 0 else spec.meat_above_peg),  # Leave meat above peg.
        ) * bd.Cylinder(
            radius=spec.mounting_hole_id / 2,
            height=spec.total_z,
            align=bde.align.ANCHOR_BOTTOM,
        )
    # Add the mounting pegs (corner holes).
    for x_val, y_val in product(
        bde.evenly_space_with_center(
            count=2,
            spacing=spec.mounting_hole_spacing_x,
        ),
        bde.evenly_space_with_center(
            count=2,
            spacing=spec.mounting_hole_spacing_y * 2,
        ),
    ):
        p += bd.Pos(x_val, y_val) * bd.Cylinder(
            radius=spec.mounting_hole_peg_od / 2,
            height=spec.mounting_hole_peg_length,
            align=bde.align.ANCHOR_TOP,
        )

    # Subtract the gap_above_top_motor.
    p -= bd.Box(
        spec.mounting_hole_spacing_x - spec.mounting_hole_id - 3,
        spec.total_y,
        spec.gap_above_top_motor,
        align=bde.align.ANCHOR_BOTTOM,
    ).translate((0, 0, spec.motor_body_length))

    return p


def make_top_plate_for_tapping(
    spec: HousingSpec,
    *,
    tap_holes: bool,
    enable_dot_6_nut_hole: bool = False,
) -> bd.Part | bd.Compound:
    """Make the threaded top plate, with holes for tapping."""
    p = bd.Part(None)

    p += bd.Box(
        spec.total_x,
        spec.total_y,
        spec.top_plate_thickness,
        align=bde.align.ANCHOR_BOTTOM,
    )

    # Add a border to get to the minimum build size for 3d printing company.
    p += bd.Box(
        spec.total_x,
        spec.total_y,
        2.1,
        align=bde.align.ANCHOR_BOTTOM,
    ) - bd.Box(
        spec.total_x - 4,
        spec.total_y - 4,
        2.1,
        align=bde.align.ANCHOR_BOTTOM,
    )

    internal_thread_for_dots = bd_warehouse.thread.TrapezoidalThread(
        diameter=spec.top_plate_dot_hole_thread_diameter,
        pitch=spec.top_plate_dot_hole_thread_pitch,
        thread_angle=30,  # Standard metric.
        length=spec.top_plate_thickness,
        external=False,
        align=bde.align.ANCHOR_BOTTOM,
    )

    # Create the dots.
    for cell_x, cell_y, dot_offset_x, dot_offset_y in product(
        bde.evenly_space_with_center(
            count=spec.cell_count_x,
            spacing=spec.cell_pitch_x,
        ),
        bde.evenly_space_with_center(
            count=spec.cell_count_y,
            spacing=spec.cell_pitch_y,
        ),
        bde.evenly_space_with_center(count=2, spacing=spec.dot_pitch_x),
        bde.evenly_space_with_center(count=3, spacing=spec.dot_pitch_y),
    ):
        dot_x = cell_x + dot_offset_x
        dot_y = cell_y + dot_offset_y

        if tap_holes:
            p -= bd.Cylinder(
                radius=spec.top_plate_dot_hole_thread_diameter / 2,
                height=spec.top_plate_thickness,
                align=bde.align.ANCHOR_BOTTOM,
            ).translate((dot_x, dot_y, 0))

            p += internal_thread_for_dots.translate((dot_x, dot_y, 0))
        elif not enable_dot_6_nut_hole:
            # Create the braille as just a cylinder.
            p -= bd.Cylinder(
                radius=spec.top_plate_tap_hole_diameter / 2,
                height=spec.top_plate_thickness,
                align=bde.align.ANCHOR_BOTTOM,
            ).translate((dot_x, dot_y, 0))

    if enable_dot_6_nut_hole:
        for cell_x, cell_y in product(
            bde.evenly_space_with_center(
                count=spec.cell_count_x,
                spacing=spec.cell_pitch_x,
            ),
            bde.evenly_space_with_center(
                count=spec.cell_count_y,
                spacing=spec.cell_pitch_y,
            ),
        ):
            # Make coords for dot 6 (for testing).
            dot_x = cell_x + spec.dot_pitch_x / 2
            dot_y = cell_y - spec.dot_pitch_y

            p -= bd.extrude(
                bd.RegularPolygon(
                    radius=3 / 2,  # Nut width of M1.6 is 3mm.
                    side_count=6,
                    major_radius=False,
                ),
                amount=10,
            ).translate((dot_x, dot_y, spec.top_plate_thickness - 1.5))

            # Remove the hole.
            p -= bd.Cylinder(
                radius=spec.top_plate_tap_hole_diameter / 2,
                height=spec.top_plate_thickness,
                align=bde.align.ANCHOR_BOTTOM,
            ).translate((dot_x, dot_y, 0))

    # Create the mounting holes.
    for hole_x, hole_y in product(
        bde.evenly_space_with_center(count=2, spacing=spec.mounting_hole_spacing_x),
        bde.evenly_space_with_center(count=3, spacing=spec.mounting_hole_spacing_y),
    ):
        p -= bd.Cylinder(
            spec.mounting_hole_id / 2,
            spec.top_plate_thickness,
            align=bde.align.ANCHOR_BOTTOM,
        ).translate((hole_x, hole_y, 0))

    return p


def write_milling_drawing_info(
    spec: HousingSpec, *, include_each_dot: bool = False
) -> str:
    """Write information for how to mill the housing."""
    lines: list[str] = []
    section_break = ["", "=" * 80, ""]

    lines.extend(
        [
            "Braille display milling machine plate dimensions:",
            "",
            "Cut stock to size:",
            f"  Housing total X: {spec.total_x}",
            f"  Housing total Y: {spec.total_y}",
            f"  Housing total Z: {spec.total_z} (not used for milling)",
            "  Stock thickness: 2mm-3mm is probably best.",
            "",
            f"Dot pitch X: {spec.dot_pitch_x}",
            f"Dot pitch Y: {spec.dot_pitch_y}",
            f"Cell pitch X: {spec.cell_pitch_x}",
            f"Cell pitch Y: {spec.cell_pitch_y}",
            f"Cell count X: {spec.cell_count_x}",
            f"Cell count Y: {spec.cell_count_y}",
            f"Total dots: {spec.cell_count_x * spec.cell_count_y * 6}",
            "",
            f"Mounting hole pitch X (2 positions): {spec.mounting_hole_spacing_x}",
            f"Mounting hole pitch Y (3 positions): {spec.mounting_hole_spacing_y}",
            "",
            "Make center of it all be at (0, 0).",
            *section_break,
        ]
    )

    # Mounting hole positions.
    hole_positions = list(
        product(
            bde.evenly_space_with_center(count=2, spacing=spec.mounting_hole_spacing_x),
            bde.evenly_space_with_center(count=3, spacing=spec.mounting_hole_spacing_y),
        )
    )
    lines.extend(
        [
            "Mounting hole positions (X, Y):",
            f"  Diameter: {spec.mounting_hole_id}",
            "",
        ]
    )
    for hole_num, (hole_x, hole_y) in enumerate(hole_positions):
        lines.extend(
            [
                f"Mounting hole {hole_num + 1} position:",
                f"  X: {hole_x}",
                f"  Y: {hole_y}",
                "",
            ]
        )

    lines.extend(section_break)

    dot_positions: list[tuple[float, float]] = []
    for cell_x, cell_y, offset_x, offset_y in product(
        bde.evenly_space_with_center(
            count=spec.cell_count_x,
            spacing=spec.cell_pitch_x,
        ),
        bde.evenly_space_with_center(
            count=spec.cell_count_y,
            spacing=spec.cell_pitch_y,
        ),
        bde.evenly_space_with_center(count=2, spacing=1),
        bde.evenly_space_with_center(count=3, spacing=1),
    ):
        dot_x = cell_x + offset_x * spec.dot_pitch_x
        dot_y = cell_y + offset_y * spec.dot_pitch_y
        dot_positions.append((dot_x, dot_y))

    lines.extend(
        [
            "Dot hole positions (X, Y):",
            "  For M1.6 tap, drill 1.25mm hole [do this].",
            "  For M1.4 tap, drill 1.1mm hole.",
            "  For other sizes, see https://fullerfasteners.com/tech/recommended-tapping-drill-size/.",
            "",
        ]
    )

    if include_each_dot:
        for dot_num, (dot_x, dot_y) in enumerate(dot_positions):
            lines.extend(
                [
                    f"Dot {dot_num + 1} position:",
                    f"  X: {dot_x}",
                    f"  Y: {dot_y}",
                    "",
                ]
            )

        lines.extend(section_break)

    # All dot X positions.
    dot_x_positions: list[float] = sorted({dot_x for dot_x, _ in dot_positions})
    dot_y_positions: list[float] = sorted({dot_y for _, dot_y in dot_positions})
    lines.append("Dot X positions:")
    lines.extend(f"  {dot_x}\n" for dot_x in dot_x_positions)
    lines.append("")

    lines.extend(section_break)

    # All dot Y positions.
    lines.append("Dot Y positions:")
    lines.extend(f"  {dot_y}\n" for dot_y in dot_y_positions)
    lines.extend(["", ""])

    return "\n".join(lines)


def two_mock_motors_joined(spec: HousingSpec) -> bd.Part | bd.Compound:
    """Make a fake motor assembly chunk, with 2 motors joined by a plate."""
    config_bottom_plate_thickness = 2
    config_extra_motor_length = 2  # Extra length so the plate is higher than flush.
    config_slop = 0.4  # Remove from diameter.

    p = bd.Part(None)

    # Add the motors.
    for motor_x in bde.evenly_space_with_center(
        count=2,
        spacing=spec.motor_pitch_x * 2,
    ):
        p += bd.Cylinder(
            radius=(spec.motor_body_od - config_slop) / 2,
            height=spec.motor_body_length + config_extra_motor_length,
            align=bde.align.ANCHOR_BOTTOM,
        ).translate(
            (
                motor_x,
                0,
                config_bottom_plate_thickness,
            ),
        )

    p += bd.Box(
        spec.motor_pitch_x * 2 + spec.motor_body_od + 1.5,
        spec.motor_body_od + 1.5,
        config_bottom_plate_thickness,
        align=bde.align.ANCHOR_BOTTOM,
    )

    # Remove a hole in the middle (wires and/or shaft).
    p -= bd.Cylinder(
        radius=2 / 2,
        height=config_bottom_plate_thickness,
        align=bde.align.ANCHOR_BOTTOM,
    )

    return p


def three_mock_thin_motors_joined(spec: HousingSpec) -> bd.Part | bd.Compound:
    """Make three cylinders the size of thin motors hulled."""
    p = bd.Part(None)

    motor_locations: list[tuple[float, float]] = [
        (-spec.motor_pitch_x, 0),
        (0, -spec.motor_pitch_y),
        (0, spec.motor_pitch_y),
    ]

    p += bd.extrude(
        # TODO(KilowattSynthesis): Open an issue and remove type ignore.
        bd.make_hull(  # type: ignore reportArgumentType
            reduce(
                lambda a, b: a + b,
                [
                    bd.Circle(radius=spec.motor_body_od / 4).translate(coord).edges()
                    for coord in motor_locations
                ],
            )
        )
        + reduce(
            lambda a, b: a + b,
            [
                bd.Circle(radius=spec.motor_body_od / 2).translate(coord)
                for coord in motor_locations
            ],
        ),
        amount=spec.slice_thickness,
    )

    return p


def solve_motor_spacing() -> None:
    """Do calculations about motor spacing."""
    _dot_pitch_x = 2.5
    cell_pitch_x = 6
    motor_od = 4

    motor_pitch_x = cell_pitch_x / 2  # Forced, so motors can hold each other.
    motor_pitch_y = sqrt(motor_od**2 - motor_pitch_x**2)
    logger.info(f"motor_pitch_y: {motor_pitch_y}")


def solve_dot_to_motor_offset_dist(spec: HousingSpec) -> None:
    """Calculate the distance from the dot to the motor."""
    dot_coords = [
        (x, y)
        for x, y in product(
            bde.evenly_space_with_center(
                count=spec.dot_count_x,
                spacing=spec.dot_pitch_x,
            ),
            bde.evenly_space_with_center(
                count=spec.dot_count_y,
                spacing=spec.dot_pitch_y,
            ),
        )
    ]

    motor_coords = [
        (x, y)
        for x, y in product(
            bde.evenly_space_with_center(
                count=spec.dot_count_x,
                spacing=spec.motor_pitch_x,
            ),
            bde.evenly_space_with_center(
                count=spec.dot_count_y,
                spacing=spec.motor_pitch_y,
            ),
        )
    ]

    for dot_num, (dot_coord, motor_coord) in enumerate(
        zip(dot_coords, motor_coords, strict=True), 1
    ):
        dot_x, dot_y = dot_coord
        motor_x, motor_y = motor_coord

        dist = sqrt((dot_x - motor_x) ** 2 + (dot_y - motor_y) ** 2)
        angle_deg = degrees(atan2(dot_y - motor_y, dot_x - motor_x))

        logger.info(
            f"Dot {dot_num} to motor dist ({motor_coord} -> {dot_coord}): "
            f"{dist:.2f} at {angle_deg:.2f}°"
        )


if __name__ == "__main__":
    start_time = datetime.now(UTC)
    py_file_name = Path(__file__).name
    logger.info(f"Running {py_file_name}")

    solve_motor_spacing()
    solve_dot_to_motor_offset_dist(HousingSpec())

    parts = {
        "three_mock_thin_motors_joined": show(
            three_mock_thin_motors_joined(HousingSpec())
        ),
        "two_mock_motors_joined": show(two_mock_motors_joined(HousingSpec())),
        "motor_housing_top_pcb": show(motor_housing(HousingSpec())),
        "motor_housing_bottom_pcb": show(
            motor_housing(
                HousingSpec(
                    motor_body_length=6.0,
                    gap_above_top_motor=0.1,
                )
            )
        ),
        "top_plate_untapped": (
            make_top_plate_for_tapping(HousingSpec(), tap_holes=False)
        ),
        "top_plate_with_dot_6_nut": (
            make_top_plate_for_tapping(
                HousingSpec(
                    top_plate_thickness=3,
                    top_plate_tap_hole_diameter=2.1,  # Clearance for M1.6.
                ),
                tap_holes=False,
                enable_dot_6_nut_hole=True,
            )
        ),
        # "top_plate_pre_tapped": ( # Very slow to generate.
        #     make_top_plate_for_tapping(HousingSpec(), tap_holes=True)
        # ),
    }

    logger.info("Saving CAD model(s)")

    (
        export_folder := Path(__file__).parent.parent / "build" / Path(__file__).stem
    ).mkdir(exist_ok=True, parents=True)
    for name, part in parts.items():
        bd.export_stl(part, str(export_folder / f"{name}.stl"))
        bd.export_step(part, str(export_folder / f"{name}.step"))

    (export_folder / "milling_drawing_info.txt").write_text(
        write_milling_drawing_info(HousingSpec())
    )

    logger.info(f"Done running {py_file_name} in {datetime.now(UTC) - start_time}")

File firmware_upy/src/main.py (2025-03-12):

# mpremote connect <port_path> mip install github:josverl/micropython-stubs/mip/typing.mpy

from typing import Literal

from machine import I2C, Pin
import time
import json

from ina219 import INA219

# Pin definitions for shift register control.
PIN_SHIFT_SER_IN = Pin(2, Pin.OUT)  # GP2: Serial data input
PIN_SHIFT_SRCK = Pin(3, Pin.OUT)  # GP3: Shift register clock
PIN_SHIFT_N_SRCLR = Pin(4, Pin.OUT)  # GP4: Shift register clear
PIN_SHIFT_RCLK = Pin(5, Pin.OUT)  # GP5: Register clock (latch)
PIN_SHIFT_N_OE = Pin(6, Pin.OUT)  # GP6: Output enable

# Constants for setting the state of the shift registers.
DOT_ADDITION_CONSTANT_UP = 0
DOT_ADDITION_CONSTANT_DOWN = 1
DOT_ADDITION_CONSTANTS = {
    "up": DOT_ADDITION_CONSTANT_UP,
    "down": DOT_ADDITION_CONSTANT_DOWN,
}

# Pin definitions for general purpose LEDs and buttons.
PIN_SW1 = Pin(28, Pin.IN, Pin.PULL_UP)
PIN_SW2 = Pin(27, Pin.IN, Pin.PULL_UP)
PIN_GP_LED_0 = Pin(7, Pin.OUT)
PIN_GP_LED_1 = Pin(8, Pin.OUT)

# Pin/Peripheral Init: INA219 Current Sensor.
INA_SHUNT_OMHS = 0.300
ina_i2c = I2C(1, scl=Pin(15), sda=Pin(14), freq=100_000)
ina: INA219  # Constructed/initialized in `init_ina()`


def init_ina() -> None:
    """Initialize INA219 current sensor. Perform I2C scan."""
    print("Scanning I2C bus for INA219.")
    i2c_addr_list: list[int] = ina_i2c.scan()
    print(f"Found {len(i2c_addr_list)} devices: {i2c_addr_list}")

    if i2c_addr_list != [0x40]:
        raise ValueError("INA219 not found at expected address.")

    global ina
    ina = INA219(ina_i2c, addr=0x40)
    ina.set_calibration_32V_2A()


def init_shift_register() -> None:
    """Initialize shift register pins to default states."""
    # Clear shift register.
    PIN_SHIFT_N_SRCLR.low()
    PIN_SHIFT_N_SRCLR.high()  # Active low, so set to normal (not clearing).

    PIN_SHIFT_N_OE.low()  # Active low, set low to enable outputs
    PIN_SHIFT_SRCK.low()  # Clock starts low
    PIN_SHIFT_RCLK.low()  # Latch starts low

    fast_clear_shift_register()

    # Clear all outputs explicity (as a precaution).
    set_shift_registers([False] * 48)


def init() -> None:
    init_shift_register()

    # Print this message after clearing the shift registers.
    # Important to do them as fast as possible on startup.
    print("Starting init.")

    PIN_GP_LED_0.low()
    PIN_GP_LED_1.low()
    init_ina()
    print("Init complete.")


def reset() -> None:
    # CLI alias.
    init()


def set_shift_registers(data: list[bool]) -> None:
    """
    Set the state of all shift registers based on input data.

    Args:
        data: list of 48 boolean values representing desired output states
             (6 registers x 8 bits per register)
    """
    start_time_us = time.ticks_us()
    if len(data) != 48:
        raise ValueError("Data must contain exactly 48 boolean values")

    # Precompute GPIO operations
    srck_set = PIN_SHIFT_SRCK.value
    ser_set = PIN_SHIFT_SER_IN.value
    rclk_set = PIN_SHIFT_RCLK.value

    # Shift out all 48 bits, MSB first
    for bit in reversed(data):
        ser_set(bit)
        srck_set(1)
        srck_set(0)

    # Latch the data to outputs
    rclk_set(1)
    rclk_set(0)

    end_time_us = time.ticks_us()
    duration_us = time.ticks_diff(end_time_us, start_time_us)
    print(f"Shift register set in {duration_us:,} us = {duration_us / 1000:.1f} ms.")


def fast_clear_shift_register() -> None:
    """Clear all shift registers.

    Duration: 700us.
    """
    # This first block here should do it, but the Chinese knockoffs don't like it:
    # # Immediately clear all shift register storage bits
    # PIN_SHIFT_N_SRCLR.low()  # Assert active-low clear
    # time.sleep_us(1)  # Short delay to ensure clear is latched
    # PIN_SHIFT_N_SRCLR.high()  # Deassert clear

    # # Latch the cleared shift register into output
    # PIN_SHIFT_RCLK.high()
    # time.sleep_us(1)  # Ensure the latch registers the cleared values
    # PIN_SHIFT_RCLK.low()

    # Get direct access to `.value()` method for speed
    ser_set = PIN_SHIFT_SER_IN.value
    srck_set = PIN_SHIFT_SRCK.value
    rclk_set = PIN_SHIFT_RCLK.value

    # Ensure data line is LOW before shifting
    ser_set(0)

    # Do 24 bits twice, so that when using only a single board,
    # its outputs are cleared first.
    for _ in range(2):
        # Shift out LOW bits (fastest possible method)
        for _ in range(24):
            srck_set(1)
            srck_set(0)

        # Latch the data to outputs
        rclk_set(1)
        rclk_set(0)


def set_all_to_each_state(
    duration_each_state_ms: int = 500, pause_duration_ms: int = 100
) -> None:
    for state in ("down", "up"):
        print(f"Setting all outputs to {state}.")

        outputs = [(i % 2 == DOT_ADDITION_CONSTANTS[state]) for i in range(48)]
        set_shift_registers(outputs)
        sleep_ms_and_log_ina_json(duration_each_state_ms)

        # Pause for a sec with outputs off.
        fast_clear_shift_register()

        if state == "down":
            time.sleep_ms(pause_duration_ms)


def set_dot(
    dot_num: int, direction: Literal["up", "down"], duration_ms: int = 0
) -> None:
    register_state = [False] * 48
    register_state[dot_num * 2 + DOT_ADDITION_CONSTANTS[direction]] = True

    set_shift_registers(register_state)

    sleep_ms_and_log_ina_json(duration_ms, log_period_ms=int(round(duration_ms / 15)))

    fast_clear_shift_register()


def cycle_dot(
    dot_num: int, duration_ms: int = 0, count: int = 10, pause_ms: int = 1000
) -> None:
    for i in range(count):
        set_dot(dot_num, "down", duration_ms)
        time.sleep_ms(pause_ms)
        set_dot(dot_num, "up", duration_ms)
        time.sleep_ms(pause_ms)


def respond_to_buttons_single_dot(dot_num: int) -> None:
    """Respond to the button presses by setting the state of `dot_num`."""

    ACTION_TIME_MS = 1
    DEBOUNCE_TIME_MS = 400

    if PIN_SW1.value() == 0:
        PIN_GP_LED_0.high()
        direction = "down"
        print(f"SW1 pressed. Push Dot {dot_num} {direction} for {ACTION_TIME_MS} ms.")

    elif PIN_SW2.value() == 0:
        PIN_GP_LED_1.high()
        direction = "up"
        print(f"SW2 pressed. Push Dot {dot_num} {direction} for {ACTION_TIME_MS} ms.")

    else:
        return

    register_state = [False] * 48
    register_state[(dot_num * 2) + DOT_ADDITION_CONSTANTS[direction]] = True

    # print(f"Setting shift registers: {register_state}")
    set_shift_registers(register_state)

    sleep_ms_and_log_ina_json(
        ACTION_TIME_MS, log_period_ms=int(round(ACTION_TIME_MS / 15))
    )

    fast_clear_shift_register()
    print("Waiting for debounce.")
    time.sleep_ms(DEBOUNCE_TIME_MS)
    PIN_GP_LED_0.low()
    PIN_GP_LED_1.low()


def demo_each_dot_one_by_one() -> None:
    for dot_num in range(24):
        print(f"Dot {dot_num} - down")
        set_dot(dot_num, "down", duration_ms=1000)

        print(f"Dot {dot_num} - up")
        set_dot(dot_num, "up", duration_ms=1000)
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

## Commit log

2025-01-10 Migrate cad from `Braille-Display-CAD` repo (#1)
2025-01-10 Migrate PCB from `Braille-Display-Inductors-CAD` repo, `pcb-type-2-rev-2` (#2)
    [Braille-PCB-Type-5-Vertical-Motors.kicad_sch, Braille_Cell.kicad_sch, Braille_Cells_and_Controls.kicad_sch]
2025-01-10 PCB: Update to have 3 motors, dimensioned layout template
    [Braille-PCB-Type-5-Vertical-Motors.kicad_sch, Braille_Cell.kicad_sch, Braille_Cells_and_Controls.kicad_sch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]
2025-01-10 PCB WIP: Add motor shaft holes
    [Braille-PCB-Type-5-Vertical-Motors.kicad_pcb, Braille-PCB-Type-5-Vertical-Motors.kicad_sch, Braille_Cell.kicad_sch]
2025-01-10 PCB WIP: More layout
    [Braille-PCB-Type-5-Vertical-Motors.kicad_pcb]
2025-01-10 PCB: Add cross-PCB connectors
    [Braille-PCB-Type-5-Vertical-Motors.kicad_pcb, Braille-PCB-Type-5-Vertical-Motors.kicad_sch, Braille_Cells_and_Controls.kicad_sch]
2025-01-11 PCB: Finish setting up power planes
    [Braille-PCB-Type-5-Vertical-Motors.kicad_pcb, Braille-PCB-Type-5-Vertical-Motors.kicad_sch]
2025-01-11 Finish Type 5 Rev 1 PCB
    [Braille-PCB-Type-5-Vertical-Motors.kicad_pcb, Braille-PCB-Type-5-Vertical-Motors.kicad_sch, Braille_Cell.kicad_sch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]
2025-01-11 PCB Rev 2: Increase shaft hole diameter from 1mm to 2mm
    [Braille-PCB-Type-5-Vertical-Motors.kicad_pcb, Braille-PCB-Type-5-Vertical-Motors.kicad_sch, Braille_Cell.kicad_sch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]
2025-02-03 pcb: in schematic, place motors closer to drivers
    [Braille-PCB-Type-5-Vertical-Motors.kicad_sch, Braille_Cell.kicad_sch, Braille_Cells_and_Controls.kicad_sch]
2025-02-04 cad: simplify housing, adapt for 2-PCB design
2025-02-08 PCB: Work on new revision
    [Braille-PCB-Type-5-Vertical-Motors.kicad_pcb, Braille-PCB-Type-5-Vertical-Motors.kicad_sch, Braille_Cell.kicad_sch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]
2025-02-08 More revision work
    [Braille-PCB-Type-5-Vertical-Motors.kicad_pcb, Braille_Cell.kicad_sch]
2025-02-08 Finish Rev 3
    [Braille-PCB-Type-5-Vertical-Motors.kicad_pcb, Braille-PCB-Type-5-Vertical-Motors.kicad_sch, Braille_Cell.kicad_sch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]
2025-02-24 cad: Bump versions
2025-02-24 cad: Add pegs for mounting holes
2025-02-24 cad: Increase motor OD to 4.5mm
2025-02-24 pcb: Bump to KiCAD v9
    [Braille-PCB-Type-5-Vertical-Motors.kicad_pcb, Braille-PCB-Type-5-Vertical-Motors.kicad_sch, Braille_Cell.kicad_sch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]
2025-02-25 cad: Add mounting holes above pegs back
2025-03-01 pcb: Add I2C address comments
    [Braille-PCB-Type-5-Vertical-Motors.kicad_sch]
2025-03-01 firmware: Add I2C current sensor code
2025-03-03 pcb: Motor driver model schematic comment
    [Braille_Cell.kicad_sch]
2025-03-03 cad: Add bushing_between_pcbs
2025-03-03 cad: Create motor-to-spacer bushing
2025-03-03 cad: Add a bit extra to the bushings
2025-03-05 cad: increase gap_above_top_motor
2025-03-13 cad: Add dot-to-motor offset calculator
2025-03-16 cad: WIP - create slightly-offset cam concept
2025-03-16 cad: Add comment about motor-to-plate spacing
2025-03-18 cad: Finish prototype screw/ramp cams
2025-03-18 cad: create the top plate parts
2025-03-18 Create printable versions of the cams
2025-06-30 chore: bump KiCAD to v9, maybe other minor changes
    [Braille-PCB-Type-5-Vertical-Motors.kicad_pcb, Braille-PCB-Type-5-Vertical-Motors.kicad_sch]
2025-08-30 cad: migrate to uv (#3)
2025-08-31 cad(hex_driver): create POC hex driver design
2025-08-31 cad(hex_driver): upgrade for metal printing POC
2025-08-31 cad(hex_driver): upgrade for metal printing POC (attempt 2)
2025-08-31 cad(hex_driver): add CNC machined variant
